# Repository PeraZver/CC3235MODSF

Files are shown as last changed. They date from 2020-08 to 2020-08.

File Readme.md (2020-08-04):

# CC3235MODSF Demo Board

Based on the CC3235MODSF LaunchPad Dev Board. The board is based around WiFi module CC3235MODSF, that contains

 - CC3235F MCU
 - 40.0-MHz crystal
 - 32.768-kHz crystal (RTC)
 - 32-Mbit SPI serial flash

## Key features

 - Dual-Band WiFi module CC3235MODSF
 - Onboard 3V3 regulator TLV1117-33
 - Onboard chip antenna M830520 
 - 4-wire JTAG and 2-wire SWD interface
 - Micro-USB connector for power and serial connections over CP2102N
 - Boot mode DIP switch
 - Some LEDs and buttons

Pero, 5/2020

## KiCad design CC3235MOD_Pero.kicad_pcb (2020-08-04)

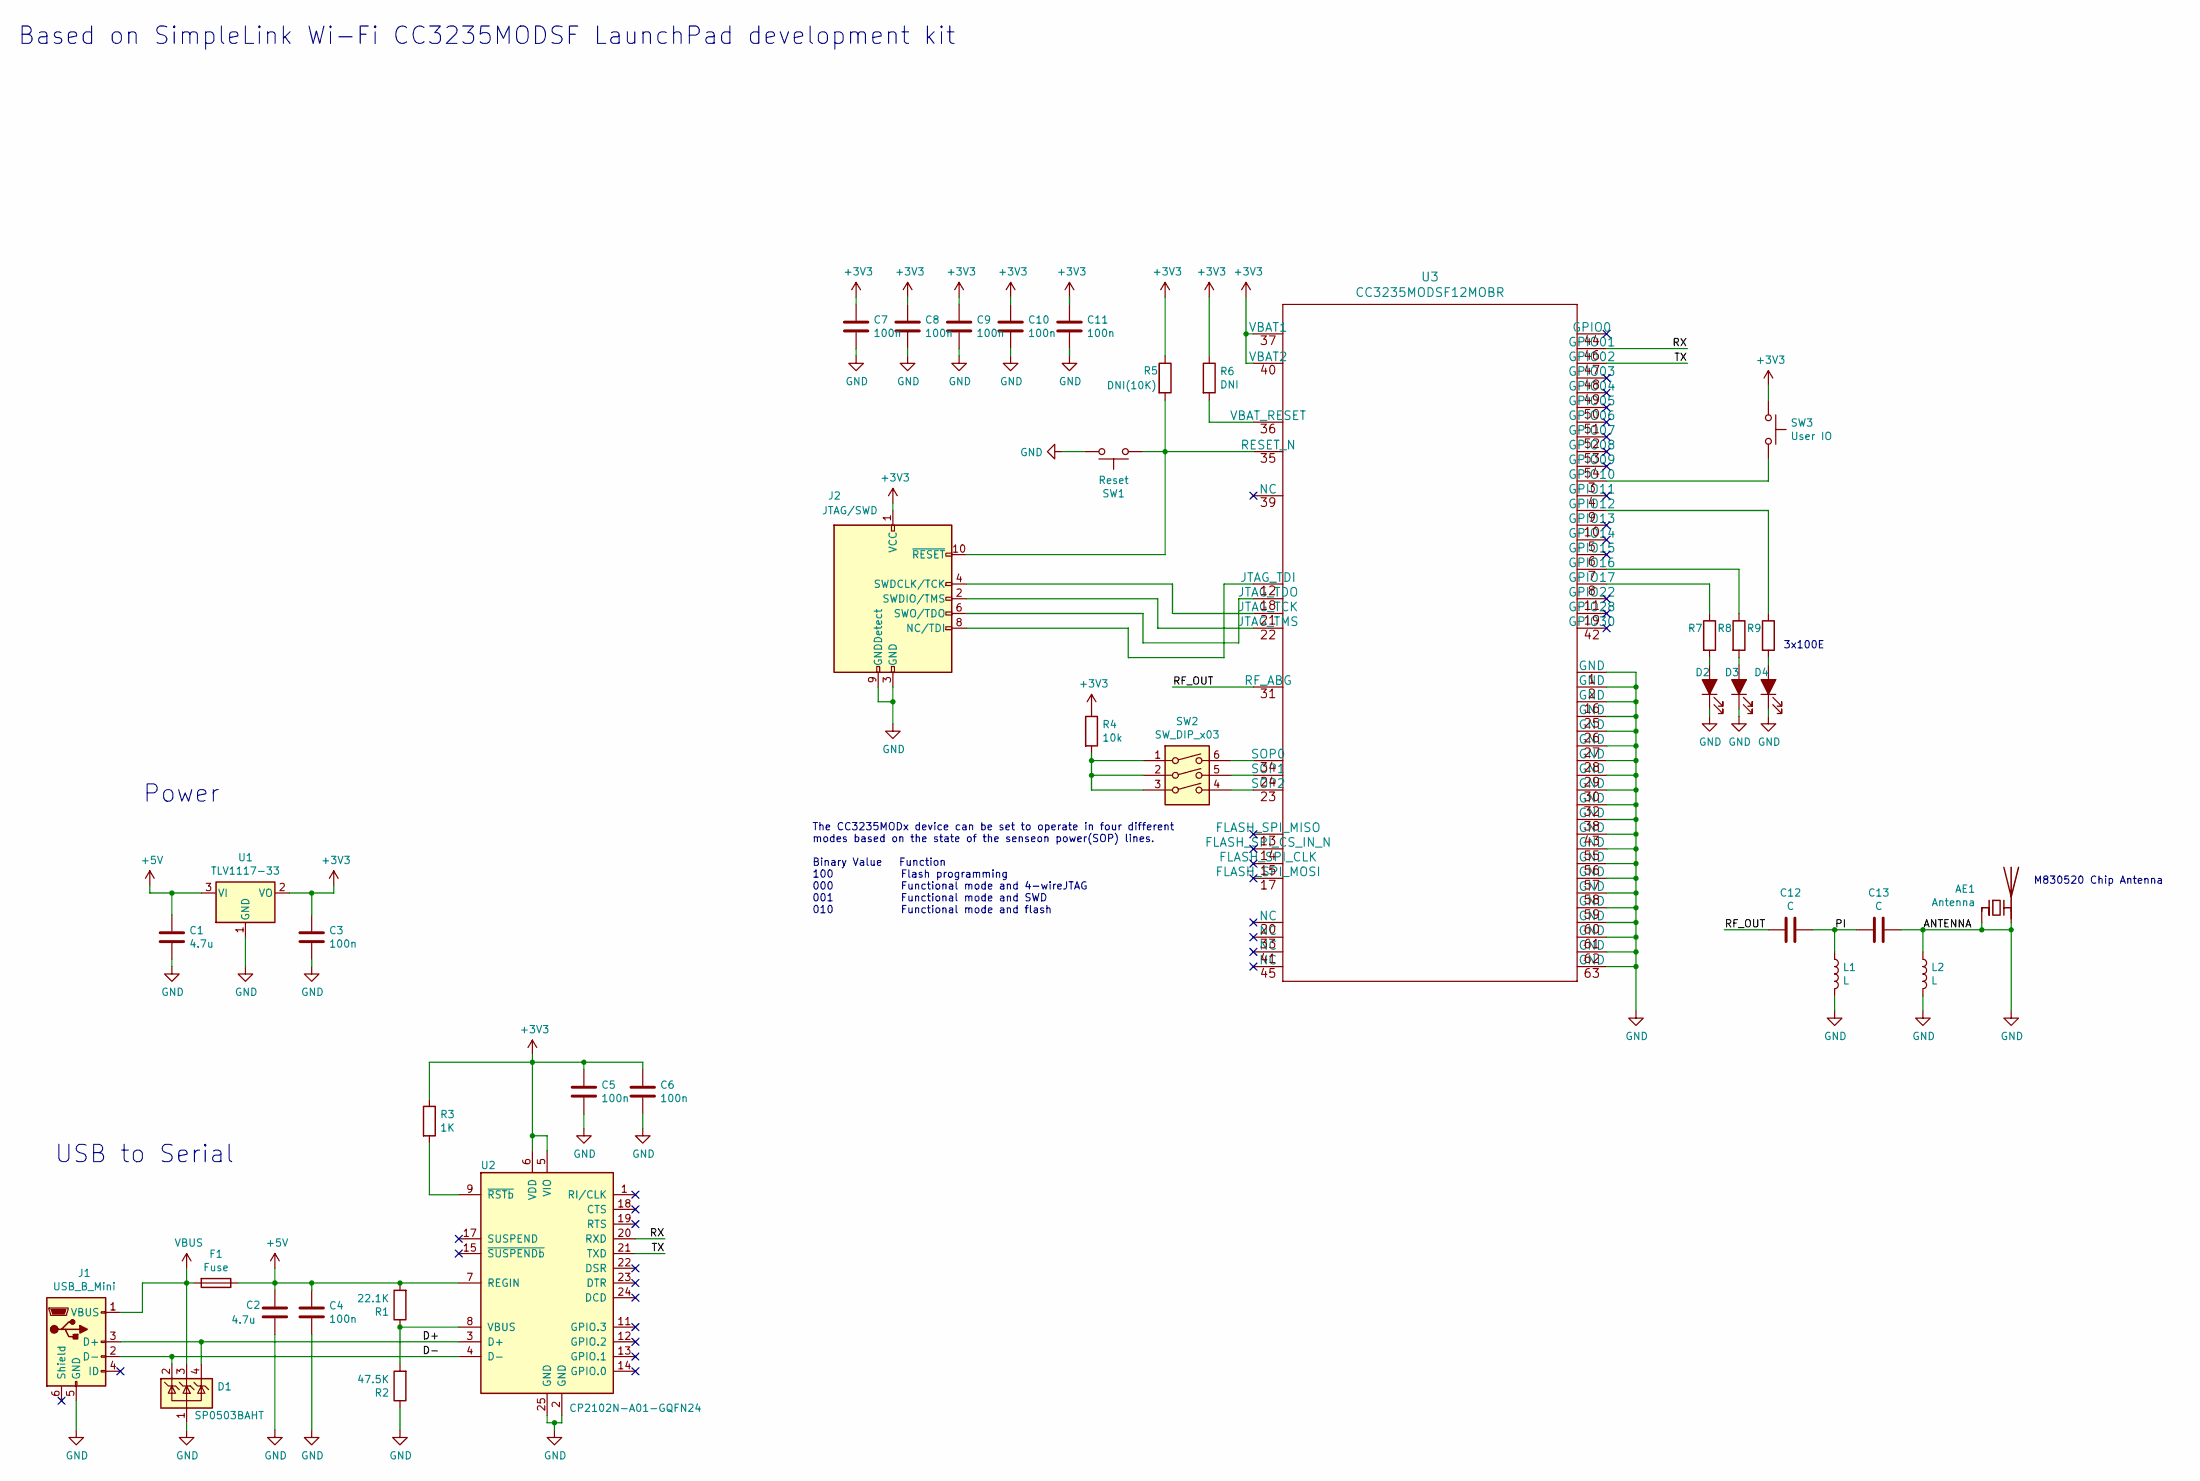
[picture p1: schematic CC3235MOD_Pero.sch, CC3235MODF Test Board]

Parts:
AE1: Antenna; M830520
C1, C2: 4.7u; C_0805
C3, C4, C5, C6, C7, C8, C9, C10, C11: 100n; C_0603
C12, C13: C; C_0603_1608Metric
D1: SP0503BAHT; SOT-143
D2, D3, D4: LED_ALT; LED_0603
F1: Fuse; Fuse_SMD1206_Reflow
J1: USB_B_Mini; USB_Micro-B_Molex-105017-0001
J2: JTAG/SWD; Pin_Header_Straight_2x05_Pitch2.54mm
L1, L2: L; L_0603
R1: 22.1K; R_0603
R2: 47.5K; R_0603
R3: 1K; R_0603
R4: 10k; R_0603
R5: DNI(10K); R_0603
R6: DNI; R_0603
R7, R8, R9: 100; R_0603
SW1: Reset; SW_SPST_EVQP0
SW2: SW_DIP_x03; SW_DIP_x3_W8.61mm_Slide_LowProfile
SW3: User IO; SW_SPST_EVQP0
U1: TLV1117-33; SOT-223-3_TabPin2
U2: CP2102N-A01-GQFN24; QFN-24-1EP_4x4mm_Pitch0.5mm
U3: CC3235MODSF12MOBR

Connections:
+3V3: C3.1, C5.1, C6.1, C7.1, C8.1, C9.1, C10.1, C11.1, J2.1 (VCC), R3.1, R4.1, R5.1, R6.1, SW3.1, U1.2 (VO), U2.5 (VIO), U2.6 (VDD), U3.37 (VBAT1), U3.40 (VBAT2)
+5V: C1.1, C2.1, C4.1, F1.1, R1.2, U1.3 (VI), U2.7 (REGIN)
/D+: D1.4 (K), J1.3 (D+), U2.3 (D+)
/D-: D1.2 (K), J1.2 (D-), U2.4 (D-)
/PI: C12.1, C13.2, L1.1
/RF_OUT: C12.2, U3.31 (RF_ABG)
/RX: U2.20 (RXD), U3.46 (GPIO01)
/TX: U2.21 (TXD), U3.47 (GPIO02)
GND: AE1.1 (FEED), AE1.2 (PCB_Trace), C1.2, C2.2, C3.2, C4.2, C5.2, C6.2, C7.2, C8.2, C9.2, C10.2, C11.2, C13.1, D1.1 (A), D2.1 (K), D3.1 (K), D4.1 (K), J1.5 (GND), J2.3 (GND), J2.5 (GND), J2.9 (GNDDetect), L1.2, L2.1, L2.2, R2.1, SW1.1, U1.1 (GND), U2.2 (GND), U2.25 (GND), U3.1 (GND), U3.2 (GND), U3.16 (GND), U3.25 (GND), U3.26 (GND), U3.27 (GND), U3.28 (GND), U3.29 (GND), U3.30 (GND), U3.32 (GND), U3.38 (GND), U3.43 (GND), U3.55 (GND), U3.56 (GND), U3.57 (GND), U3.58 (GND), U3.59 (GND), U3.60 (GND), U3.61 (GND), U3.62 (GND), U3.63 (GND), U3.V
unnamed: D2.2 (A), R7.2
unnamed: D3.2 (A), R8.2
unnamed: D4.2 (A), R9.2
unnamed: J2.2 (SWDIO/TMS), U3.22 (JTAG_TMS)
unnamed: J2.4 (SWDCLK/TCK), U3.21 (JTAG_TCK)
unnamed: J2.6 (SWO/TDO), U3.18 (JTAG_TDO)
unnamed: J2.8 (NC/TDI), U3.12 (JTAG_TDI)
unnamed: J2.10 (~RESET~), R5.2, SW1.2, U3.35 (RESET_N)
unnamed: R1.1, R2.2, U2.8 (VBUS)
unnamed: R3.2, U2.9 (~RSTb)
unnamed: R4.2, SW2.1, SW2.2, SW2.3
unnamed: R6.2, U3.36 (VBAT_RESET)
unnamed: R7.1, U3.8 (GPIO17)
unnamed: R8.1, U3.7 (GPIO16)
unnamed: R9.1, U3.9 (GPIO12)
unnamed: SW2.4, U3.23 (SOP2)
unnamed: SW2.5, U3.24 (SOP1)
unnamed: SW2.6, U3.34 (SOP0)
unnamed: SW3.2, U3.3 (GPIO10)
VBUS: D1.3 (K), F1.2, J1.1 (VBUS)

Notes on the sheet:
M830520 Chip Antenna
The CC3235MODx device can be set to operate in four different modes based on the state of the senseon power(SOP) lines. Binary Value Function 100 Flash programming 000 Functional mode and 4-wireJTAG 001 Functional mode and SWD 010 Functional mode and flash
Based on SimpleLink Wi-Fi CC3235MODSF LaunchPad development kit
USB to Serial
Power
3x100E

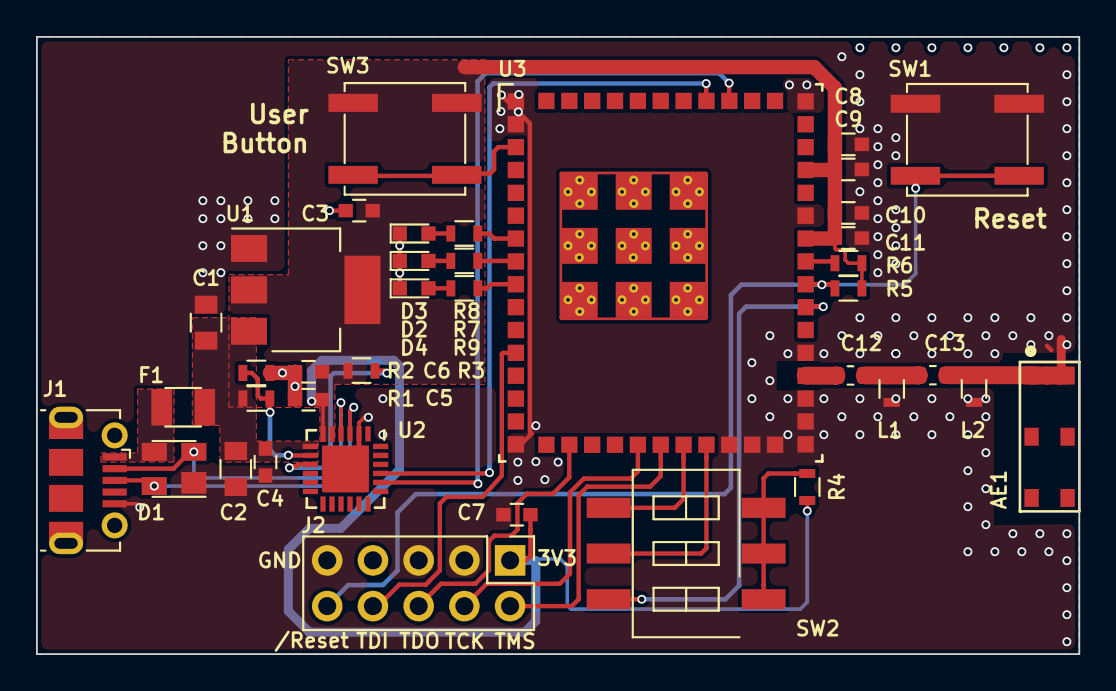
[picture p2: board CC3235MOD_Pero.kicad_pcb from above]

Board: 2 copper layers, 57.9 x 34.3 mm, 38 parts (0 on the bottom side), 29 nets.

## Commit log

2020-05-20 initial commit, go some symbols
    [CC3235MOD_Pero.kicad_pcb, CC3235MOD_Pero.sch]
2020-05-20 added some generic components
    [CC3235MOD_Pero.sch]
2020-05-20 added CP2102N for USB connection
    [CC3235MOD_Pero.sch]
2020-05-22 sch finished
    [CC3235MOD_Pero.sch]
2020-05-22 assign footprints, started layout
    [CC3235MOD_Pero.kicad_pcb, CC3235MOD_Pero.sch]
2020-06-14 antenna footprint done
    [CC3235MOD_Pero.kicad_pcb, CC3235MOD_Pero.sch]
2020-06-14 placement going
    [CC3235MOD_Pero.kicad_pcb, CC3235MOD_Pero.sch]
2020-06-18 placement done
    [CC3235MOD_Pero.kicad_pcb, CC3235MOD_Pero.sch]
2020-06-19 routing 90%
    [CC3235MOD_Pero.kicad_pcb, CC3235MOD_Pero.sch]
2020-06-19 fixint antenna footprint
    [CC3235MOD_Pero.kicad_pcb, CC3235MOD_Pero.sch]
2020-06-22 silkscreen references
    [CC3235MOD_Pero.kicad_pcb]
2020-06-22 keepout on rf trace
    [CC3235MOD_Pero.kicad_pcb]
2020-06-22 fixed rf filter placement
    [CC3235MOD_Pero.kicad_pcb]
2020-06-22 antenna gnd solved
    [CC3235MOD_Pero.kicad_pcb, CC3235MOD_Pero.sch]
2020-06-22 50Ohm trace adapted for 1.6mm PCB
    [CC3235MOD_Pero.kicad_pcb]
2020-06-22 via stitching
    [CC3235MOD_Pero.kicad_pcb]
2020-06-22 silkscreen finished, ready to order
    [CC3235MOD_Pero.kicad_pcb]
2020-06-22 adding a hash number
    [CC3235MOD_Pero.kicad_pcb]
2020-06-22 SWD silkscreen
    [CC3235MOD_Pero.kicad_pcb]
2020-08-04 adding readme
    [CC3235MOD_Pero.kicad_pcb]
2020-08-04 fixed footprint associations AGAIN!
    [CC3235MOD_Pero.sch]
